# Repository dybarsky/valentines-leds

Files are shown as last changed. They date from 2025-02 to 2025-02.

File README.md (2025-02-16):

## HEART LEDs Valentine's day gift.
An Open Source & Open Hardware project.  

_Demo gif (loads a bit long)_ 👇  


## Parts
The core of this project is `MSP430G2553` mictrocontroller by Texas Instruments and two `SN74HC595N` 8-bit shift registers. Each 8-bit shift register controls 8 3mm red LEDs. Also resistors, capacitors, slide switch, tacticle button, DIP sockets, Li-ion akku 3.7V, a JST connector.  

Check schematics below to get values for resistors and capacitors.  

Here are all used components 👇  


And this is how assembly looks like 👇  


## Schematic
I used KiCad to design hardware. Source files are located in `pcb` folder.  
This is a schematic diagram 👇


## PCB Design
KiCad project fies for PCB as well as Gerber files for PCB production are also located in `pcb` fodler.  
This is a PCB design 👇  
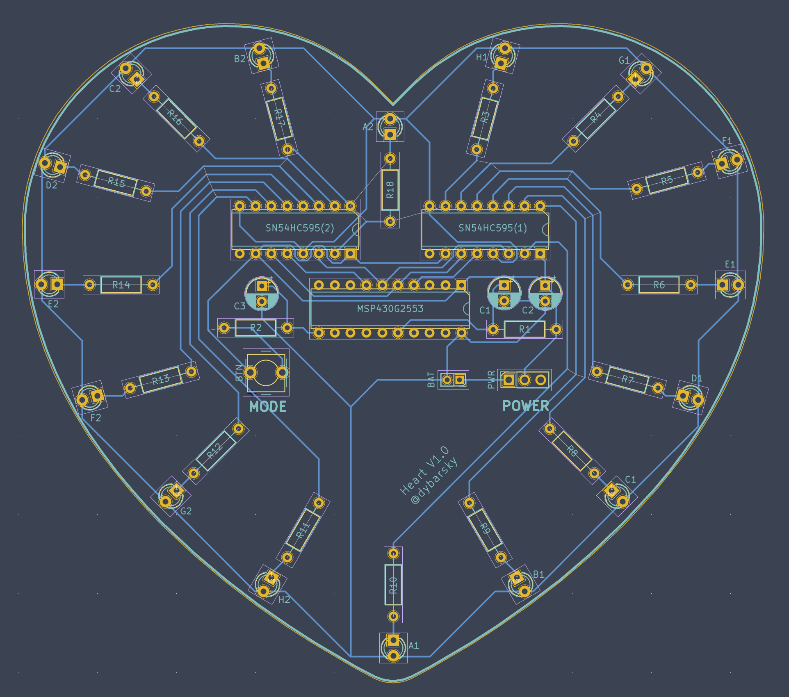
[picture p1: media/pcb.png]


With highlighted nets 👇  
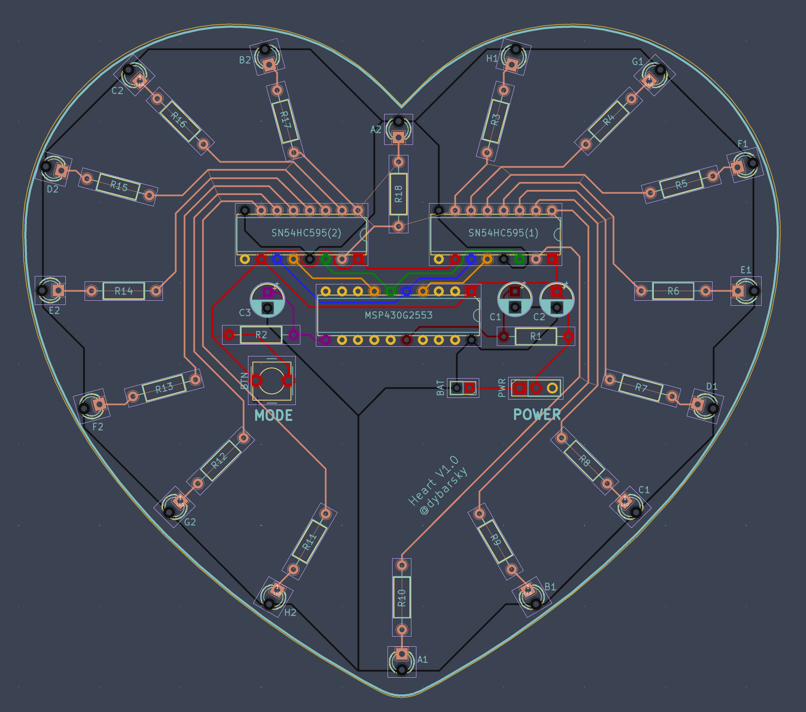
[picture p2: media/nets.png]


## Firmware
Firmware for this project was written in pure `C`, operating with IC registers directly (without platformio or any other ports of arduino libraries). It requires some deeper knowledge of MSP430G2553 datasheet and hardware communication protocols, but drastically reduces binary size. It's only 14 KB!  

There are 6 different patterns of LEDs blinking. They are store in 2 dimensional arrays of bytes.  
Timer intrruptions are configured to be called every 0.1 second. IC goes over array and sends data to 8-bit shift register. Communication between the microcontroller and 8-bit shift registers is done via `SPI` protocol. When IC is not busy, it goes to low power mode.

## Demo
https://www.youtube.com/watch?v=liG8lNvPkbY

## Instrucitons 
https://www.instructables.com/Electronic-Heart-Valentines-Day-Gift/

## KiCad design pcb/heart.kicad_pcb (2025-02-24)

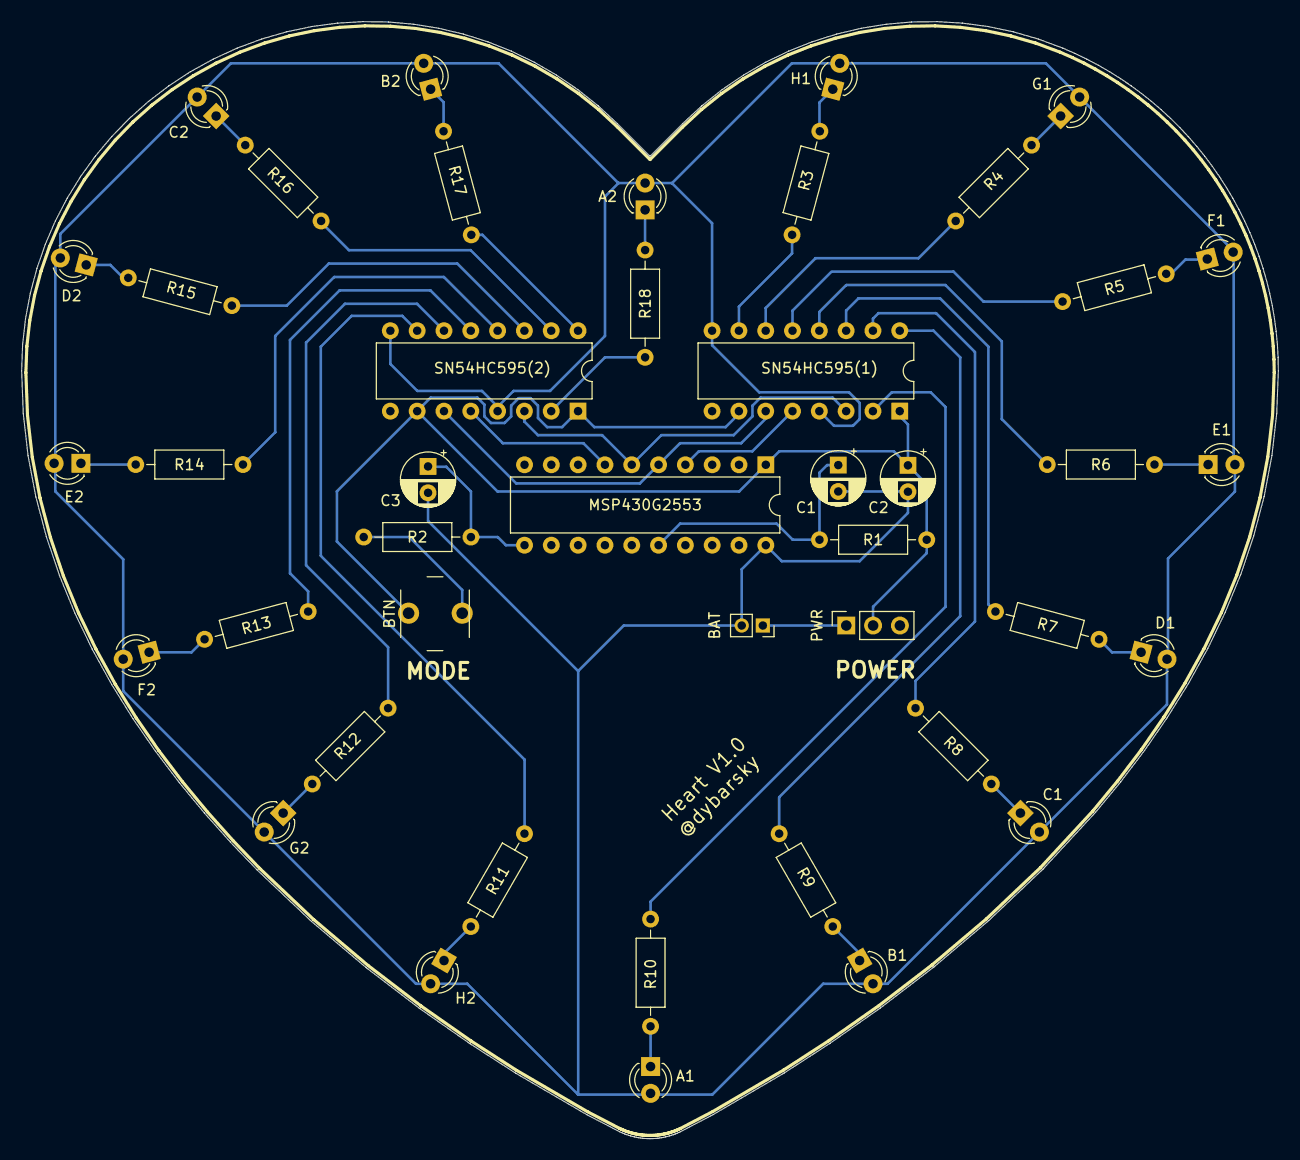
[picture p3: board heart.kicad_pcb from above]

Board: 2 copper layers, 119.1 x 105.8 mm, 43 parts (0 on the bottom side), 9 nets.

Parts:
A1, A2: LED_D3.0mm
B1, B2: LED_D3.0mm
BAT: PinSocket_1x02_P2.00mm_Vertical
BTN: SW_PUSH_6mm_H5mm
C1, C2#2: LED_D3.0mm
C1#2, C2, C3: CP_Radial_D5.0mm_P2.50mm
D1, D2: LED_D3.0mm
E1, E2: LED_D3.0mm
F1, F2: LED_D3.0mm
G1, G2: LED_D3.0mm
H1, H2: LED_D3.0mm
MSP430G2553: DIP-20_W7.62mm
PWR: PinSocket_1x03_P2.54mm_Vertical
R1, R2, R3, R4, R5, R6, R7, R8, R9, R10, R11, R12, R13, R14, R15, R16, R17, R18: R_Axial_DIN0207_L6.3mm_D2.5mm_P10.16mm_Horizontal
SN54HC595(1), SN54HC595(2): DIP-16_W7.62mm

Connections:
BTN: C3.1, MSP430G2553.11, R2.1
CLK: MSP430G2553.5, SN54HC595(1).11, SN54HC595(2).11
DAT: MSP430G2553.6, SN54HC595(1).14, SN54HC595(2).14
GND: A1.2, A2.2, B1.2, B2.2, BAT.2, C1.2, C1#2.2, C2.2, C2#2.2, C3.2, D1.2, D2.2, E1.2, E2.2, F1.2, F2.2, G1.2, G2.2, H1.2, H2.2, MSP430G2553.20, SN54HC595(1).8, SN54HC595(1).13, SN54HC595(2).8, SN54HC595(2).13
LED: A1.1, A2.1, B1.1, B2.1, C1.1, C2#2.1, D1.1, D2.1, E1.1, E2.1, F1.1, F2.1, G1.1, G2.1, H1.1, H2.1, R3.1, R3.2, R4.1, R4.2, R5.1, R5.2, R6.1, R6.2, R7.1, R7.2, R8.1, R8.2, R9.1, R9.2, R10.1, R10.2, R11.1, R11.2, R12.1, R12.2, R13.1, R13.2, R14.1, R14.2, R15.1, R15.2, R16.1, R16.2, R17.1, R17.2, R18.1, R18.2, SN54HC595(1).1, SN54HC595(1).2, SN54HC595(1).3, SN54HC595(1).4, SN54HC595(1).5, SN54HC595(1).6, SN54HC595(1).7, SN54HC595(1).15, SN54HC595(2).1, SN54HC595(2).2, SN54HC595(2).3, SN54HC595(2).4, SN54HC595(2).5, SN54HC595(2).6, SN54HC595(2).7, SN54HC595(2).15
LTCH1: MSP430G2553.4, SN54HC595(1).12
LTCH2: MSP430G2553.7, SN54HC595(2).12
RST: C1#2.1, MSP430G2553.16, R1.1
VCC: BAT.1, BTN.1, BTN.2, C2.1, MSP430G2553.1, PWR.1, PWR.2, R1.2, R2.2, SN54HC595(1).10, SN54HC595(1).16, SN54HC595(2).10, SN54HC595(2).16

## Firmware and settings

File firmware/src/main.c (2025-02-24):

#include <msp430g2553.h>
#include "shift.h"
#include "timer.h"
#include "button.h"
#include "pattern.h"

void configure() {
	// turn off watchdog
	WDTCTL = WDTPW + WDTHOLD;
	// set frequency 1MHz
	BCSCTL1 = CALBC1_1MHZ;
	DCOCTL = CALDCO_1MHZ;
	// set all pins off
	P1OUT = 0;
	P2OUT = 0;
}

pattern current;
static unsigned char index;

int main(void) {
	// config peripherals
	configure();
	configure_timer();
	configure_shift();
	configure_button();
	// turn off leds
	shift_a(0);
	shift_b(0);
	// init state
	index = 0;
	current = next_pattern();
	start_timer();
	// low power mode + enable interruptions
	_BIS_SR(LPM0_bits + GIE);
}

void on_button_callback() {
	index = 0;
	current = next_pattern();
}

void on_timer_callback() {
	if (index >= current.size) {
		index = 0;
	}
	unsigned char *row = current.array + (index * 2);
	unsigned char left = row[0];
	unsigned char right = row[1];
	shift_b(left);
	shift_a(right);
	index ++;
}

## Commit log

2025-02-05 Add timer control
2025-02-05 Add button control
2025-02-05 Add schematics
    [heart.kicad_pcb, heart.kicad_sch]
2025-02-11 Fix button.c
2025-02-12 Move pcb files one folder up
    [heart-B_Cu.gbr, heart-B_Mask.gbr, heart-B_Paste.gbr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]
2025-02-14 Remove name from silkscreen
    [heart.kicad_pcb]
2025-02-14 Add version and author to silkscreen
    [heart.kicad_pcb]
2025-02-16 Update gerber files
    [heart-B_Cu.gbr, heart-B_Mask.gbr, heart-B_Paste.gbr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]
2025-02-24 Update pcb design
    [heart.kicad_pcb]
